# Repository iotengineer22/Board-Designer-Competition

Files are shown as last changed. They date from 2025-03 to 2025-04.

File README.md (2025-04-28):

# Board-Designer-Competition
This repository present solution for the Board Designer Competition 

[Board Designer Competition](https://www.hackster.io/contests/board-designer).

## Introduction
**First of all thank you to Nordic Semiconductor, Autodesk, PCBWay and hackster.io for hosting this exciting competition.**

The main project is primarily summarized on hackster.io, so please refer to it there 

[Maker's nRF54L15 Debug Board](https://www.hackster.io/iotengineer22/maker-s-nrf54l15-debug-board-1a6a88)

In this project, we provide Maker's nRF54L15 Debug Board. We have designed a compact board featuring the powerful nRF54L15 Wireless SOC.

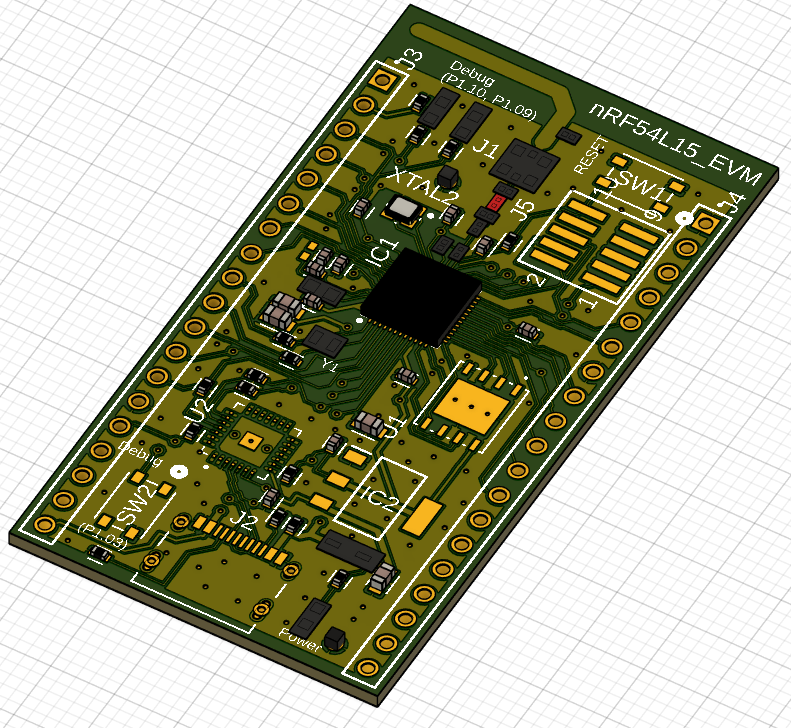
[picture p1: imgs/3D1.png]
3D1


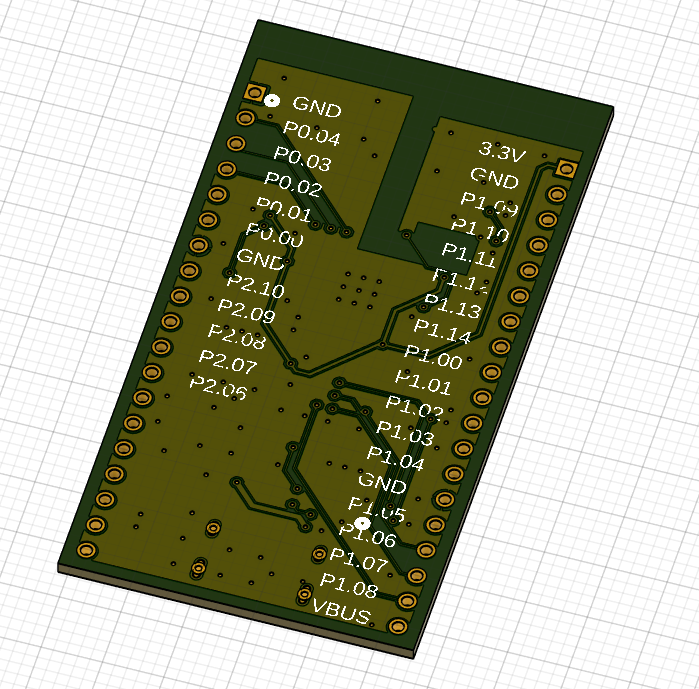
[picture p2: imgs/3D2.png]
3D2


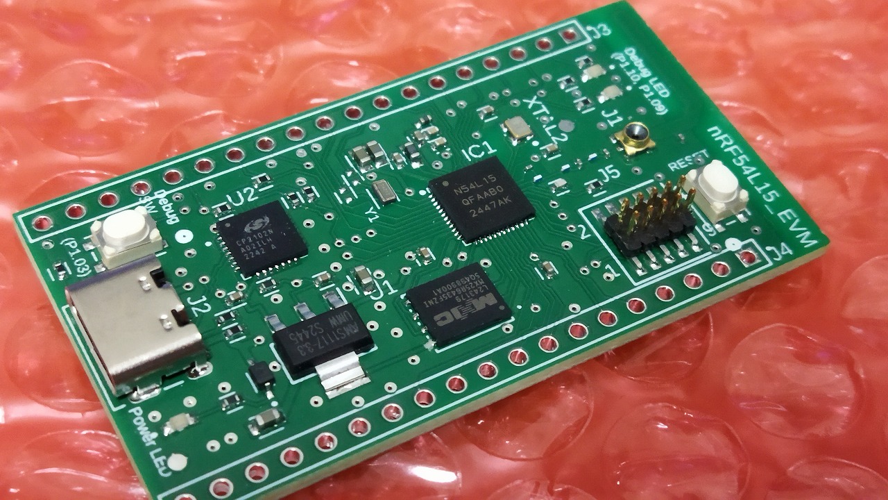
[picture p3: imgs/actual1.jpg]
ac1


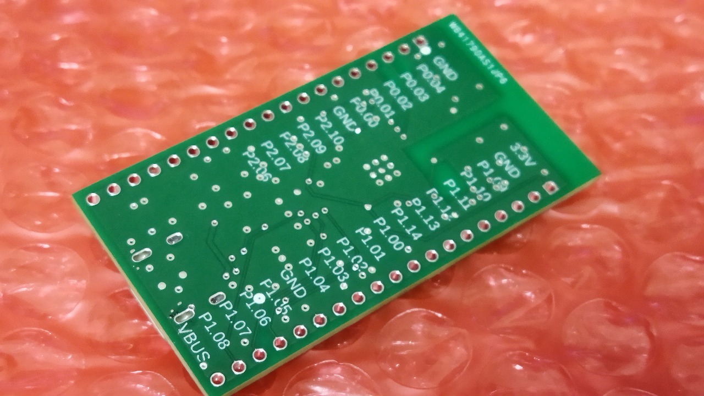
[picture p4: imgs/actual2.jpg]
ac2


## Structure
    .
    ├── pcb                 # PCB files(autodesk, gerber, bom, schematics)   
    ├── src                 # Program and board files (program, board)   
    ├── LICENSE
    └── README.md

## Electrical Diagram overview

This is Main electrical diagram.

**For details, see the PDF file.**
[PDF schematics](pcb/schematics)

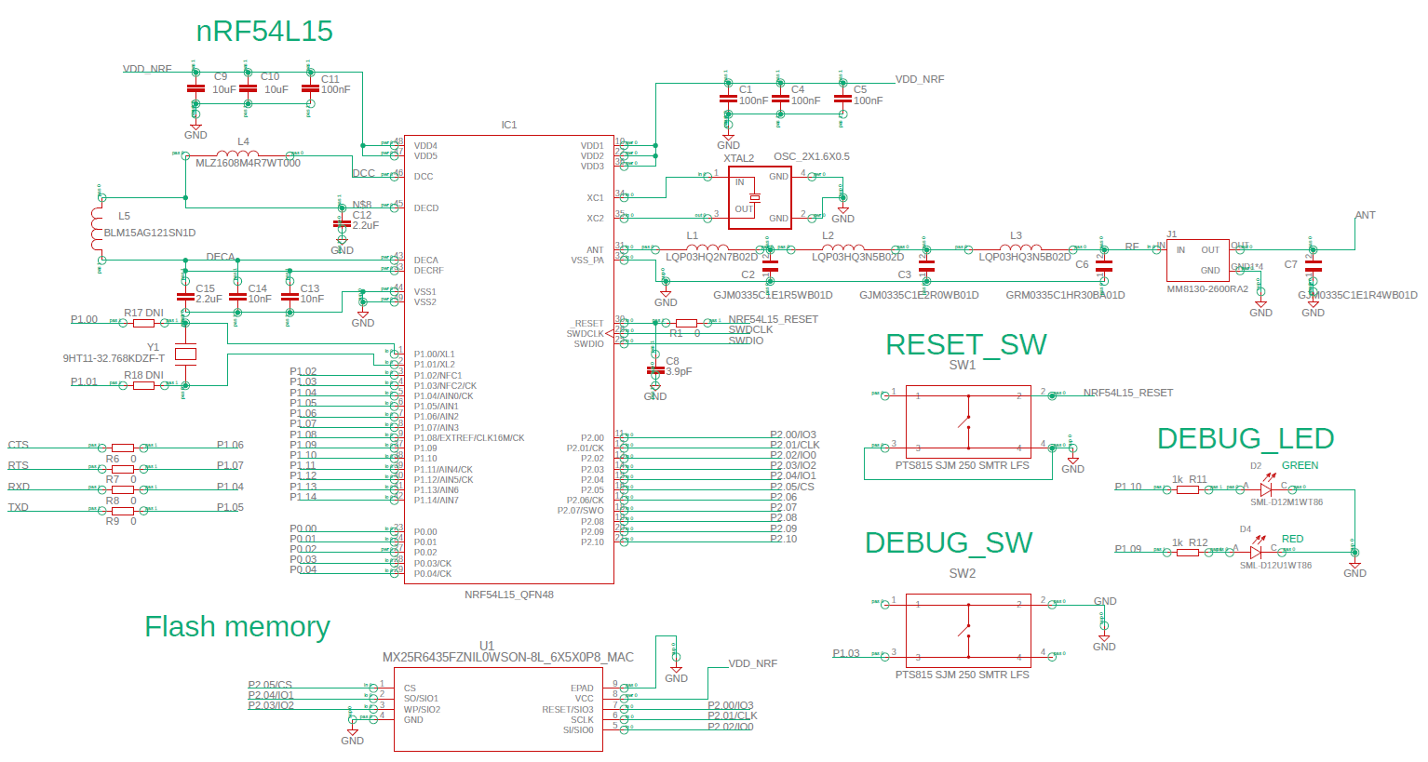
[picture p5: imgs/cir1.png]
schematics1


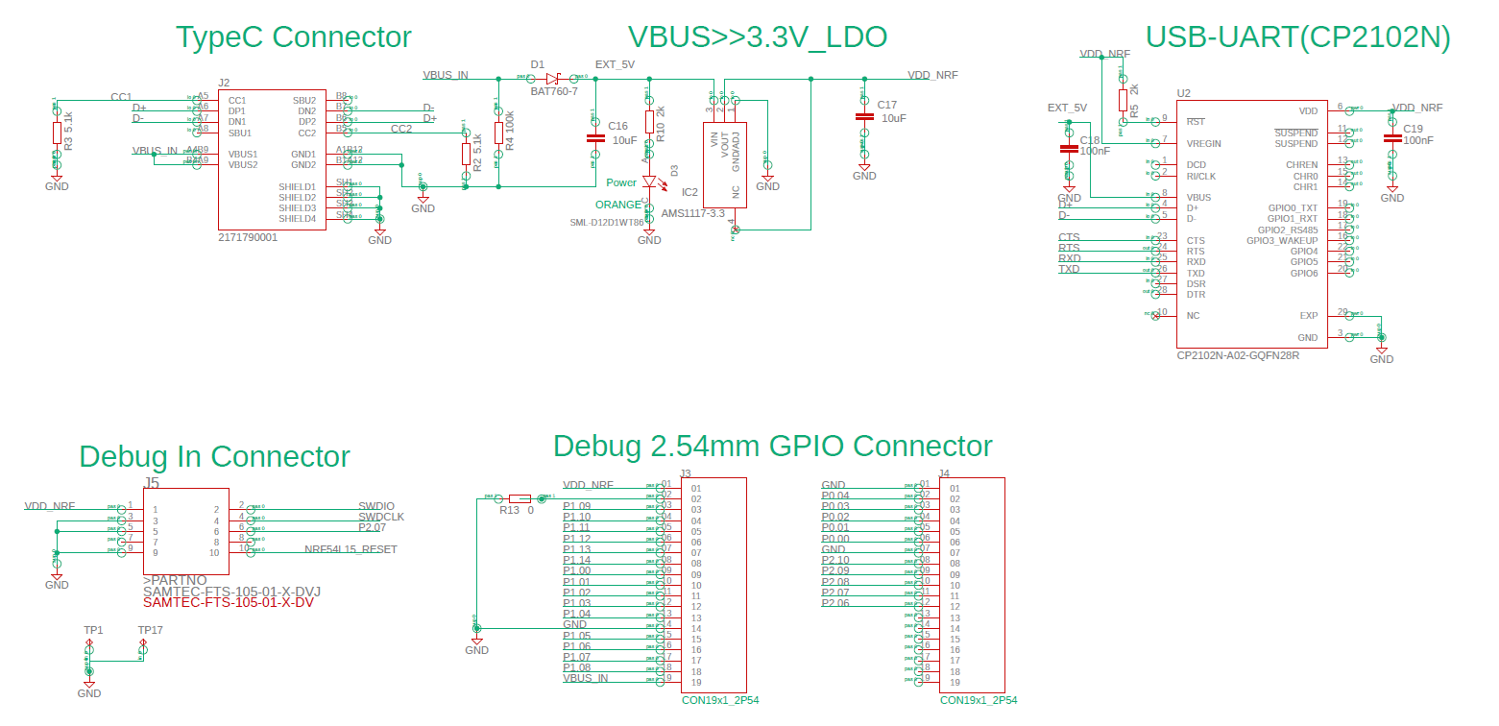
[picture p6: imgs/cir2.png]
schematics2


## PCB ArtWork overview

This is Artwork overview.

**For details, see the PCB files in Autodesk Fusion or Gerber data.**

[Autodesk_project_file](pcb/autodesk)

[Gerber_data](pcb/gerber)

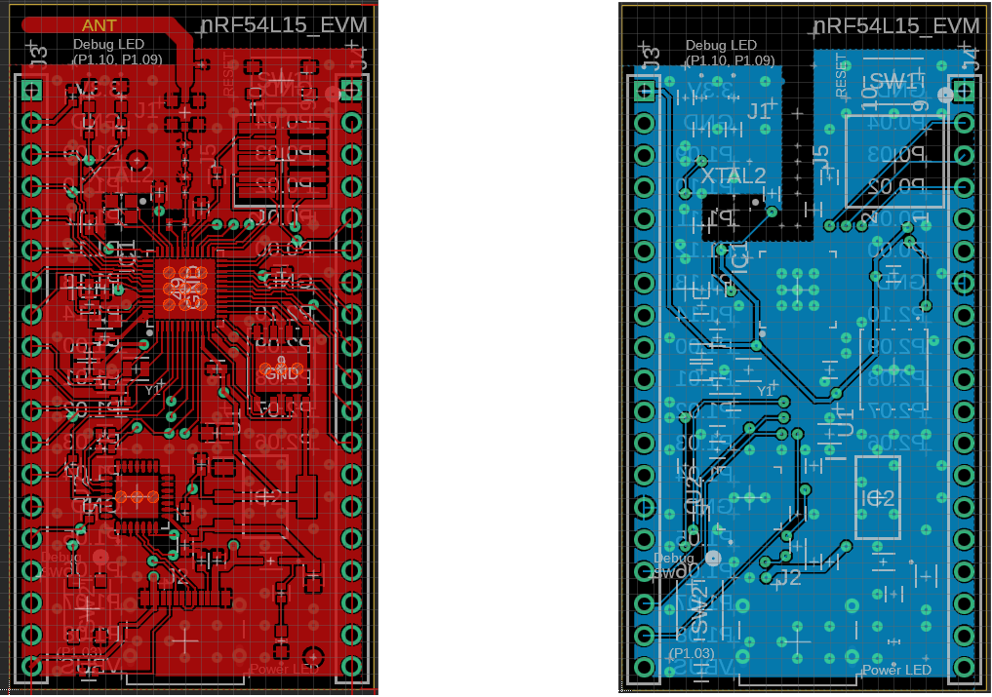
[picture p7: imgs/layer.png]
artwork1


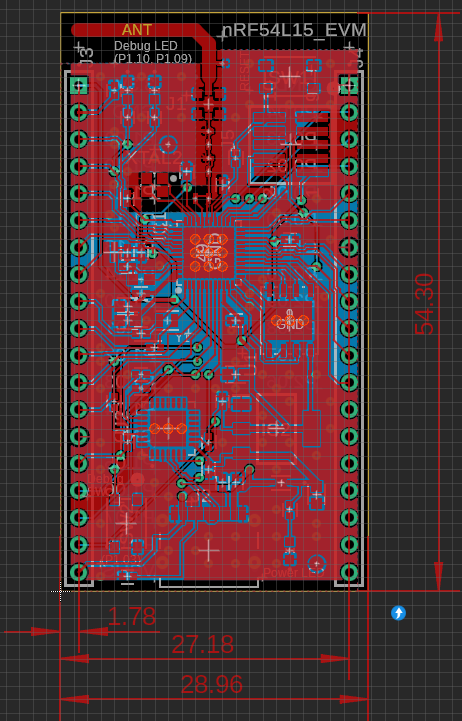
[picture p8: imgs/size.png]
artwork2


## PCB BOM

This is BOM overview.

**For details, see the BOM data(.xlsx).**

[BOM_file](pcb/bom)

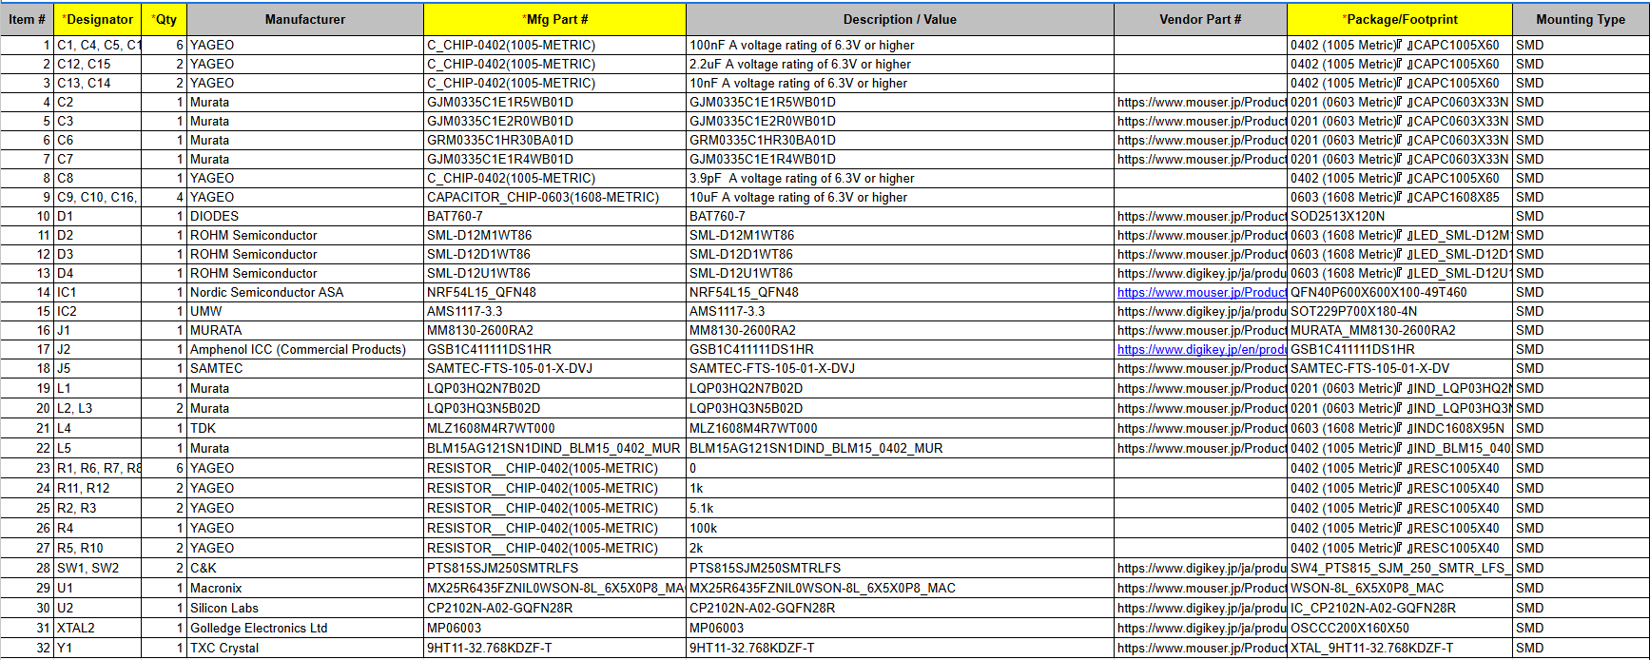
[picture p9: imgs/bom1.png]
bom1


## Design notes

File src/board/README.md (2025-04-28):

## Refernce

This board file references the following repository:https://github.com/zephyrproject-rtos/zephyr/tree/main/boards/nordic/nrf54l15dk

v2.9.0

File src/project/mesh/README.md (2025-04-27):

## Refernce

This program references the following repository:
Using the reference program directly.
https://github.com/nrfconnect/sdk-nrf/tree/main/samples/bluetooth/mesh/chat

Note: The my board file for this project does not support Non-Secure mode. Therefore, the nRF54L15-DK board file is being used for this test.

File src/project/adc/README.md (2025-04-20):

## Refernce

This program references the following repository:https://github.com/zephyrproject-rtos/zephyr/tree/main/samples/drivers/adc/adc_sequence

Note: This test requires the addition of an ADC device tree. We are using the configuration file for the nRF54L15-DK.

Make sure to configure it using "Extra Devicetree overlays" during board configuration.

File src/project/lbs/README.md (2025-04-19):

## Refernce

This program references the following repository:
https://github.com/nrfconnect/sdk-nrf/tree/main/samples/bluetooth/peripheral_lbs

Note: The my board file for this project does not support Non-Secure mode. Therefore, the nRF54L15-DK board file is being used for this test.

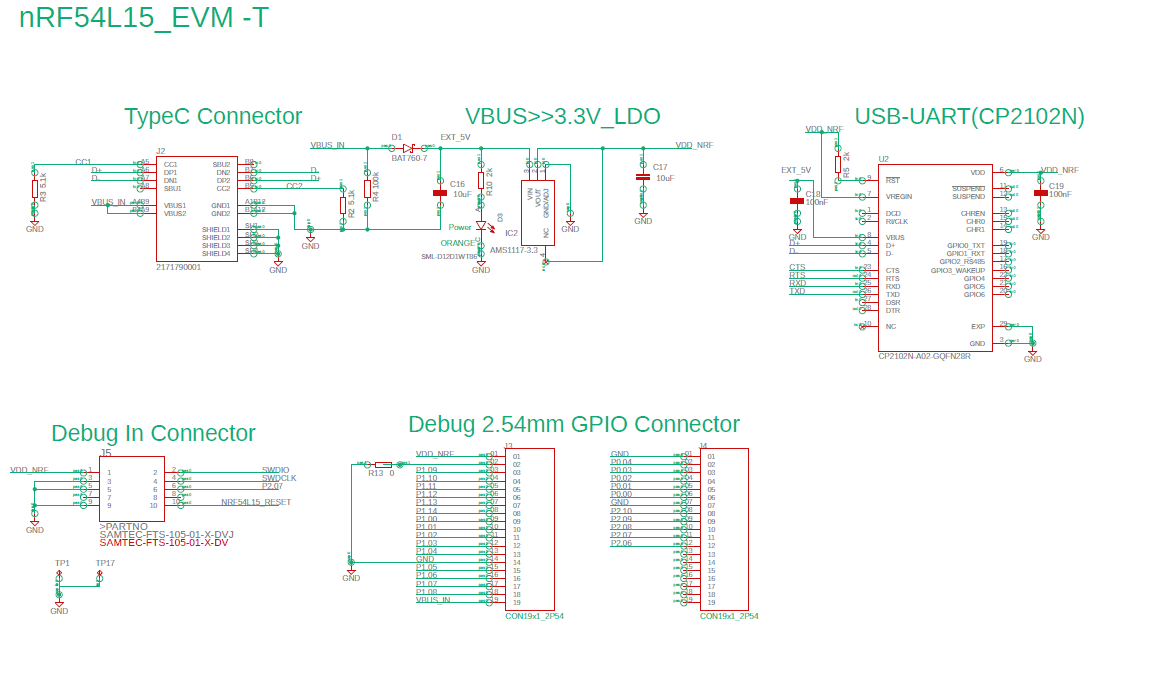
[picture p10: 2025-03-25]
imgs/schematics1.png

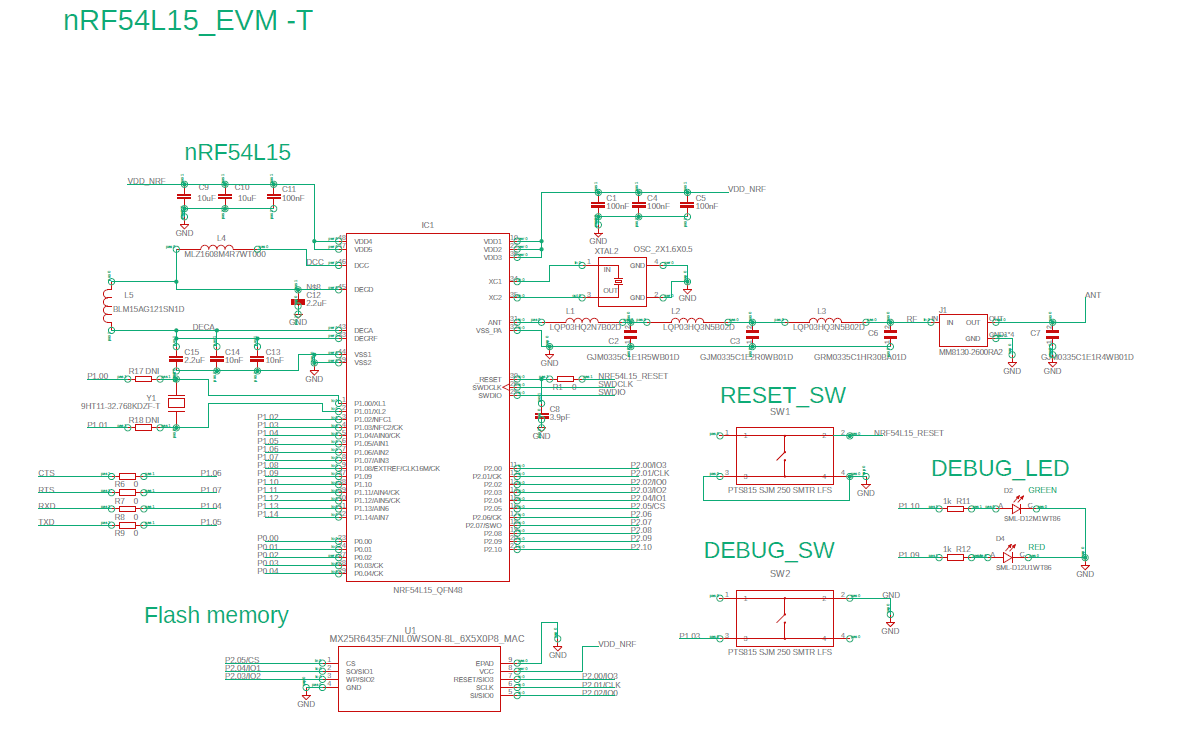
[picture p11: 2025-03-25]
imgs/schematics2.png

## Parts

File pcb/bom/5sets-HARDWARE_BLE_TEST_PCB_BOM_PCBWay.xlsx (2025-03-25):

PCBWay Bom Quotation, Product No.
Item # | *Designator | *Qty | Manufacturer | *Mfg Part # | Description / Value | Vendor Part # | *Package/Footprint | Mounting Type | *Unit Price(5 sets) | *Total | *Delivery Time | *Actual Purchase Mfg Part # | Customer Reply | PCBWay Update
1 | C1, C4, C5, C11, C18, C19 | 6 | YAGEO | C_CHIP-0402(1005-METRIC) | 100nF A voltage rating of 6.3V or higher |  | 0402 (1005 Metric)『 』CAPC1005X60 | SMD | $0.005 | $0.150 |  | CC0402KRX7R5BB104
2 | C12, C15 | 2 | YAGEO | C_CHIP-0402(1005-METRIC) | 2.2uF A voltage rating of 6.3V or higher |  | 0402 (1005 Metric)『 』CAPC1005X60 | SMD | $0.050 | $0.500 |  | CC0402MRX5R5BB225
3 | C13, C14 | 2 | YAGEO | C_CHIP-0402(1005-METRIC) | 10nF A voltage rating of 6.3V or higher |  | 0402 (1005 Metric)『 』CAPC1005X60 | SMD | $0.016 | $0.160 |  | CC0402KRX7R5BB103
4 | C2 | 1 | Murata | GJM0335C1E1R5WB01D | GJM0335C1E1R5WB01D | https://www.mouser.jp/ProductDetail/Murata-Electronics/GJM0335C1E1R5WB01D?qs=YLLXL5qGyDs1VzYPuYV7Xw%3D%3D | 0201 (0603 Metric)『 』CAPC0603X33N | SMD | $0.105 | $0.525
5 | C3 | 1 | Murata | GJM0335C1E2R0WB01D | GJM0335C1E2R0WB01D | https://www.mouser.jp/ProductDetail/Murata-Electronics/GJM0335C1E2R0WB01D?qs=YLLXL5qGyDstavpxLCdNYQ%3D%3D | 0201 (0603 Metric)『 』CAPC0603X33N | SMD | $0.088 | $0.440
6 | C6 | 1 | Murata | GRM0335C1HR30BA01D | GRM0335C1HR30BA01D | https://www.mouser.jp/ProductDetail/Murata-Electronics/GRM0335C1HR30BA01D?qs=7vGxPDjevFM20tgZc05ZRA%3D%3D | 0201 (0603 Metric)『 』CAPC0603X33N | SMD | $0.063 | $0.315
7 | C7 | 1 | Murata | GJM0335C1E1R4WB01D | GJM0335C1E1R4WB01D | https://www.mouser.jp/ProductDetail/Murata-Electronics/GJM0335C1E1R4WB01D?qs=YLLXL5qGyDv2Ga7DIq6Zqw%3D%3D | 0201 (0603 Metric)『 』CAPC0603X33N | SMD | $0.273 | $1.365
8 | C8 | 1 | YAGEO | C_CHIP-0402(1005-METRIC) | 3.9pF A voltage rating of 6.3V or higher |  | 0402 (1005 Metric)『 』CAPC1005X60 | SMD | $0.050 | $0.250 |  | CC0402BRNPO9BN3R9
9 | C9, C10, C16, C17 | 4 | YAGEO | CAPACITOR_CHIP-0603(1608-METRIC) | 10uF A voltage rating of 6.3V or higher |  | 0603 (1608 Metric)『 』CAPC1608X85 | SMD | $0.037 | $0.740 |  | CC0603MRX5R5BB106
10 | D1 | 1 | DIODES | BAT760-7 | BAT760-7 | https://www.mouser.jp/ProductDetail/Diodes-Incorporated/BAT760-7?qs=JV7lzlMm3yKDDyO09xoRbQ%3D%3D | SOD2513X120N | SMD | $0.110 | $0.550
11 | D2 | 1 | ROHM Semiconductor | SML-D12M1WT86 | SML-D12M1WT86 | https://www.mouser.jp/ProductDetail/ROHM-Semiconductor/SML-D12M1WT86?qs=M3jcYzEJUdHoswTb5Zs%252BhA%3D%3D | 0603 (1608 Metric)『 』LED_SML-D12M1WT86 | SMD | $0.169 | $0.845
12 | D3 | 1 | ROHM Semiconductor | SML-D12D1WT86 | SML-D12D1WT86 | https://www.mouser.jp/ProductDetail/ROHM-Semiconductor/SML-D12D1WT86?qs=M3jcYzEJUdEqFdUV5eljZg%3D%3D | 0603 (1608 Metric)『 』LED_SML-D12D1WT86 | SMD | $0.189 | $0.945
13 | D4 | 1 | ROHM Semiconductor | SML-D12U1WT86 | SML-D12U1WT86 | https://www.digikey.jp/ja/products/detail/rohm-semiconductor/SML-D12U1WT86/5843853 | 0603 (1608 Metric)『 』LED_SML-D12U1WT86 | SMD | $0.176 | $0.880
14 | IC1 | 1 | Nordic Semiconductor ASA | NRF54L15_QFN48 | NRF54L15_QFN48 | https://www.mouser.jp/ProductDetail/Nordic-Semiconductor/NRF54L15-CAAA-R?qs=QpmGXVUTftEz0ltGbbtKyA%3D%3D | QFN40P600X600X100-49T460 | SMD | $4.797 | $23.985 | 7-10 Workdays | NRF54L15-QFAA-R
15 | IC2 | 1 | UMW | AMS1117-3.3 | AMS1117-3.3 | https://www.digikey.jp/ja/products/detail/umw/AMS1117-3-3/17635254 | SOT229P700X180-4N | SMD | $0.110 | $0.550
16 | J1 | 1 | MURATA | MM8130-2600RA2 | MM8130-2600RA2 | https://www.mouser.jp/ProductDetail/Murata-Electronics/MM8130-2600RA2?qs=pwh76yelNxAj%2FSz0%2FLo03A%3D%3D | MURATA_MM8130-2600RA2 | SMD | $0.483 | $2.415
17 | J2 | 1 | Amphenol ICC (Commercial Products) | GSB1C411111DS1HR | GSB1C411111DS1HR | https://www.digikey.jp/en/products/detail/amphenol-cs-commercial-products/GSB1C411111DS1HR/21623895 | GSB1C411111DS1HR | SMD |  |  |  | GSB1C411111DS1HR
18 | J5 | 1 | SAMTEC | SAMTEC-FTS-105-01-X-DVJ | SAMTEC-FTS-105-01-X-DVJ | https://www.mouser.jp/ProductDetail/Samtec/FTS-105-01-F-DV?qs=FESYatJ8odJViphOhsc8lQ%3D%3D | SAMTEC-FTS-105-01-X-DV | SMD | $1.771 | $8.855 |  | FTS-105-01-F-DV
19 | L1 | 1 | Murata | LQP03HQ2N7B02D | LQP03HQ2N7B02D | https://www.mouser.jp/ProductDetail/Murata-Electronics/LQP03HQ2N7B02D?qs=Ey7%2FXF42M3c4mqXFWTJuBA%3D%3D | 0201 (0603 Metric)『 』IND_LQP03HQ2N7B02D | SMD | $0.105 | $0.525
20 | L2, L3 | 2 | Murata | LQP03HQ3N5B02D | LQP03HQ3N5B02D | https://www.mouser.jp/ProductDetail/Murata-Electronics/LQP03HQ3N5B02D?qs=Ey7%2FXF42M3czaOgYp0oGuw%3D%3D | 0201 (0603 Metric)『 』IND_LQP03HQ3N5B02D | SMD | $0.231 | $2.310
21 | L4 | 1 | TDK | MLZ1608M4R7WT000 | MLZ1608M4R7WT000 | https://www.mouser.jp/ProductDetail/TDK/MLZ1608M4R7WT000?qs=%2FPzWLGNeQ%252BgDMtsNiWmi%252BQ%3D%3D | 0603 (1608 Metric)『 』INDC1608X95N | SMD | $0.097 | $0.485
22 | L5 | 1 | Murata | BLM15AG121SN1DIND_BLM15_0402_MUR | BLM15AG121SN1DIND_BLM15_0402_MUR | https://www.mouser.jp/ProductDetail/Murata-Electronics/BLM15AG121SN1D?qs=0mZ9c%252Bni6FbHnpaodfEgFg%3D%3D | 0402 (1005 Metric)『 』IND_BLM15_0402_MUR | SMD | $0.050 | $0.250 |  | BLM15AG121SN1D
23 | R1, R6, R7, R8, R9, R13 | 6 | YAGEO | RESISTOR__CHIP-0402(1005-METRIC) | 0 |  | 0402 (1005 Metric)『 』RESC1005X40 | SMD | $0.003 | $0.090 |  | RC0402FR-070RL
24 | R11, R12 | 2 | YAGEO | RESISTOR__CHIP-0402(1005-METRIC) | 1k |  | 0402 (1005 Metric)『 』RESC1005X40 | SMD | $0.013 | $0.130 |  | RC0402FR-071KL
25 | R2, R3 | 2 | YAGEO | RESISTOR__CHIP-0402(1005-METRIC) | 5.1k |  | 0402 (1005 Metric)『 』RESC1005X40 | SMD | $0.013 | $0.130 |  | RC0402FR-075K1L
26 | R4 | 1 | YAGEO | RESISTOR__CHIP-0402(1005-METRIC) | 100k |  | 0402 (1005 Metric)『 』RESC1005X40 | SMD | $0.016 | $0.080 |  | RC0402FR-07100KL
27 | R5, R10 | 2 | YAGEO | RESISTOR__CHIP-0402(1005-METRIC) | 2k |  | 0402 (1005 Metric)『 』RESC1005X40 | SMD | $0.013 | $0.130 |  | RC0402FR-072KL
28 | SW1, SW2 | 2 | C&K | PTS815SJM250SMTRLFS | PTS815SJM250SMTRLFS | https://www.digikey.jp/ja/products/detail/c-k/PTS815-SJM-250-SMTR-LFS/9947846 | SW4_PTS815_SJM_250_SMTR_LFS_CN | SMD | $0.247 | $2.470
29 | U1 | 1 | Macronix | MX25R6435FZNIL0WSON-8L_6X5X0P8_MAC | MX25R6435FZNIL0WSON-8L_6X5X0P8_MAC | https://www.mouser.jp/ProductDetail/Macronix/MX25R6435FZNIL0-TR?qs=mELouGlnn3eItee4ycFGCQ%3D%3D | WSON-8L_6X5X0P8_MAC | SMD | $2.403 | $12.015 | 7-10 Workdays | MX25R6435FZNIL0-TR
30 | U2 | 1 | Silicon Labs | CP2102N-A02-GQFN28R | CP2102N-A02-GQFN28R | https://www.digikey.jp/ja/products/detail/silicon-labs/CP2102N-A02-GQFN28R/9863480 | IC_CP2102N-A02-GQFN28R | SMD | $2.415 | $12.075
31 | XTAL2 | 1 | Golledge Electronics Ltd | MP06003 | MP06003 | https://www.digikey.jp/ja/products/detail/golledge-electronics-ltd/MP06003/16965329 | OSCCC200X160X50 | SMD | $0.599 | $2.995 | 7-10 Workdays
32 | Y1 | 1 | TXC Crystal | 9HT11-32.768KDZF-T | 9HT11-32.768KDZF-T | https://www.mouser.jp/ProductDetail/TXC-Corporation/9HT11-32.768KDZF-T?qs=F0DCslhVfvzZjS075r2oeA%3D%3D | XTAL_9HT11-32.768KDZF-T | SMD | $1.143 | $5.715 | 7-10 Workdays
 |  |  |  |  |  |  |  |  | Component Cost | $82.87
 |  |  |  |  |  |  |  |  | Assembly Cost | $88.00
 |  |  |  |  |  |  |  |  | PCB Cost | $5.00
 |  |  |  |  |  |  |  |  | V0 Member 0% off | $0.00
 |  |  |  |  |  |  |  |  | All Total 5 Sets | $175.87

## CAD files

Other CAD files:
pcb/autodesk/hardware_ble_test v68.f3z

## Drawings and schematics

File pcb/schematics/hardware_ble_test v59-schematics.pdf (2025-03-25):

pas 1 | pas 1 pas 0 pas 1 | pas 1 pas 1 | pas 1 pas 1

# nRF54L15

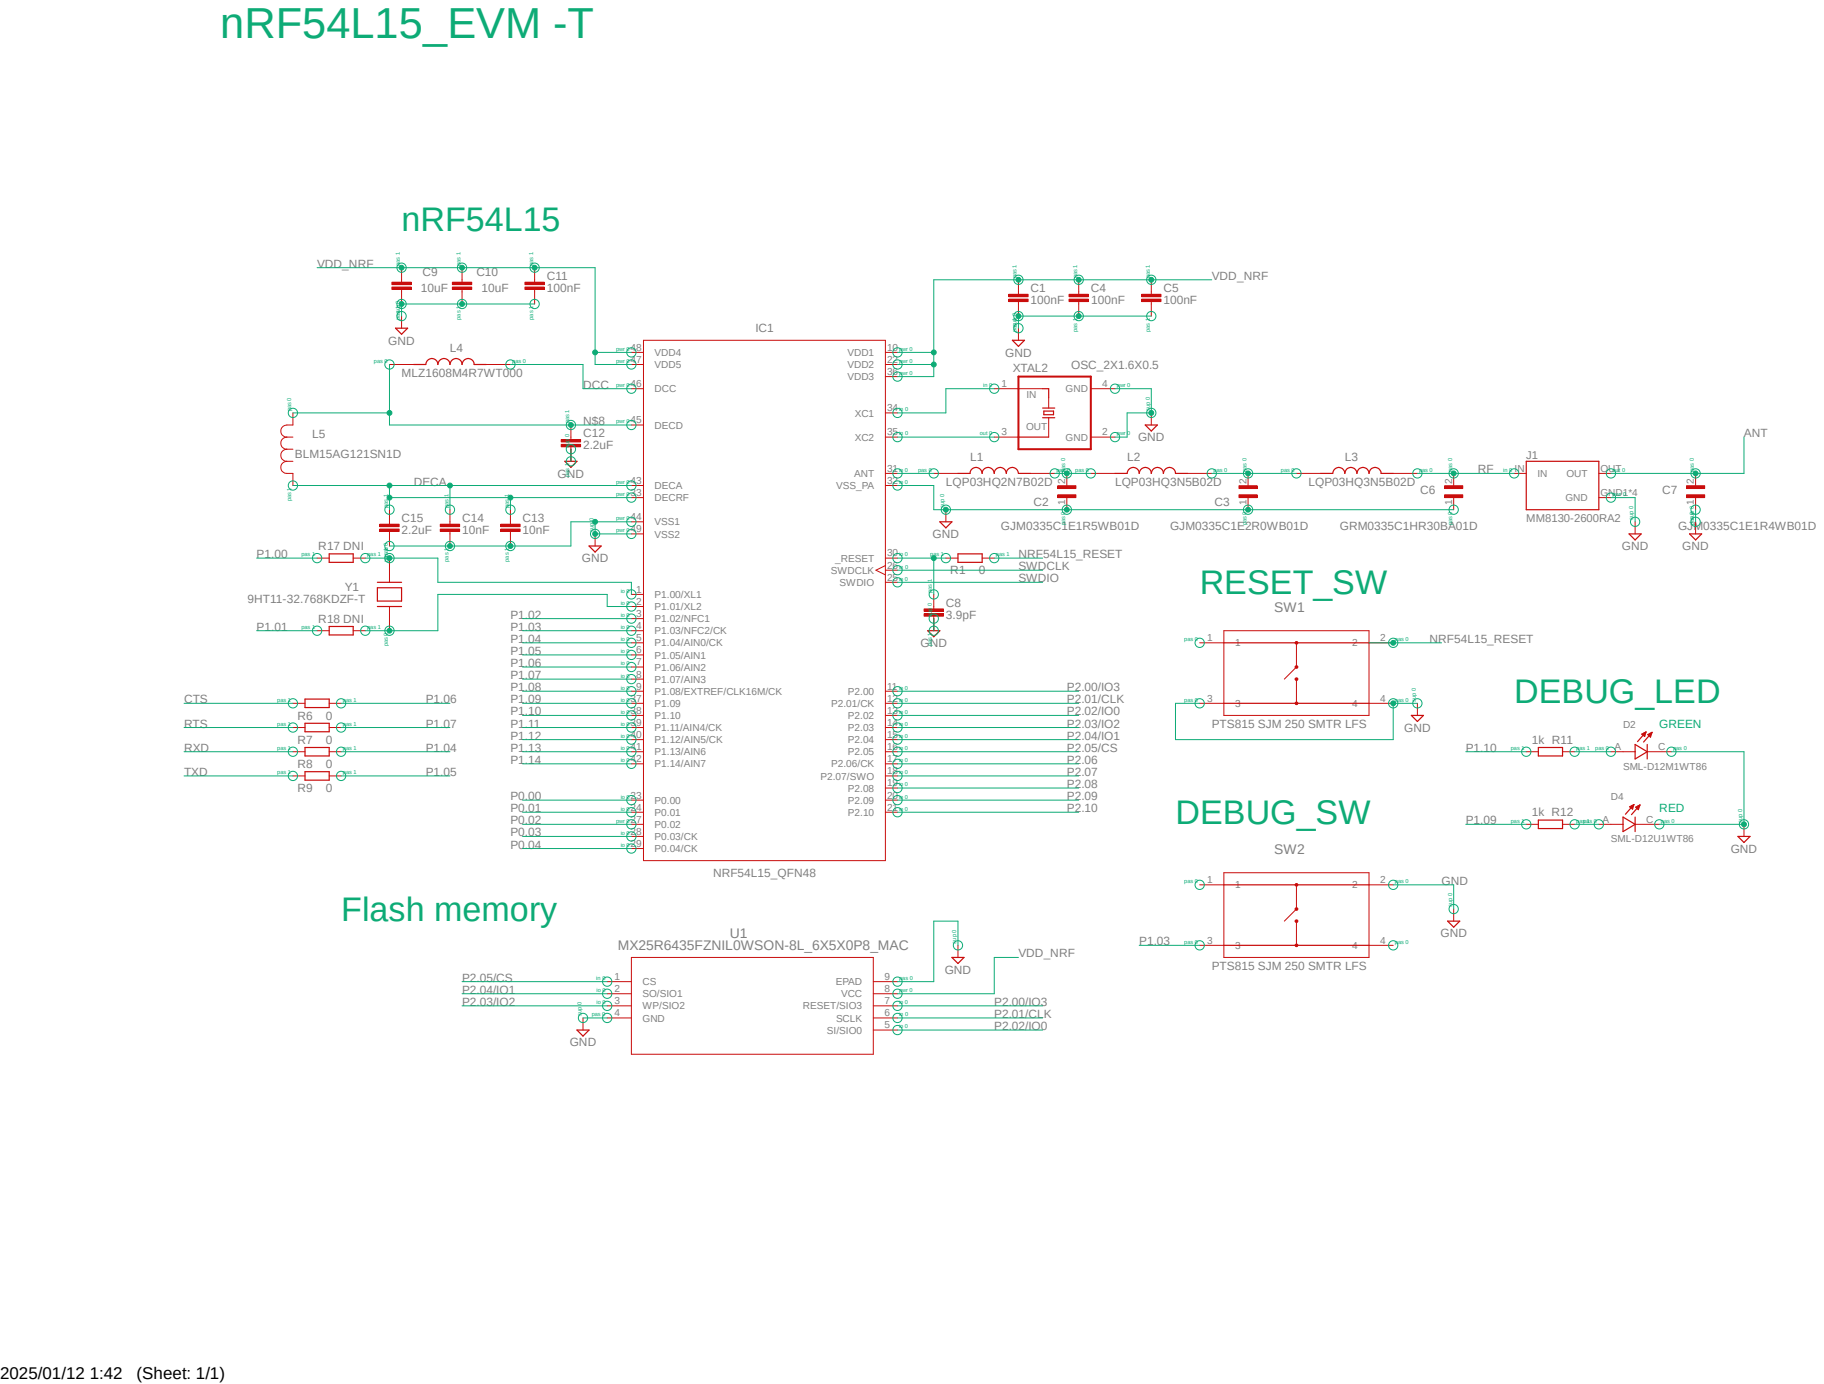
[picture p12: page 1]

pwr 0

SAMTEC-FTS-105-01-X-DV in 0 sup 0 | sup 0

# TypeC Connector

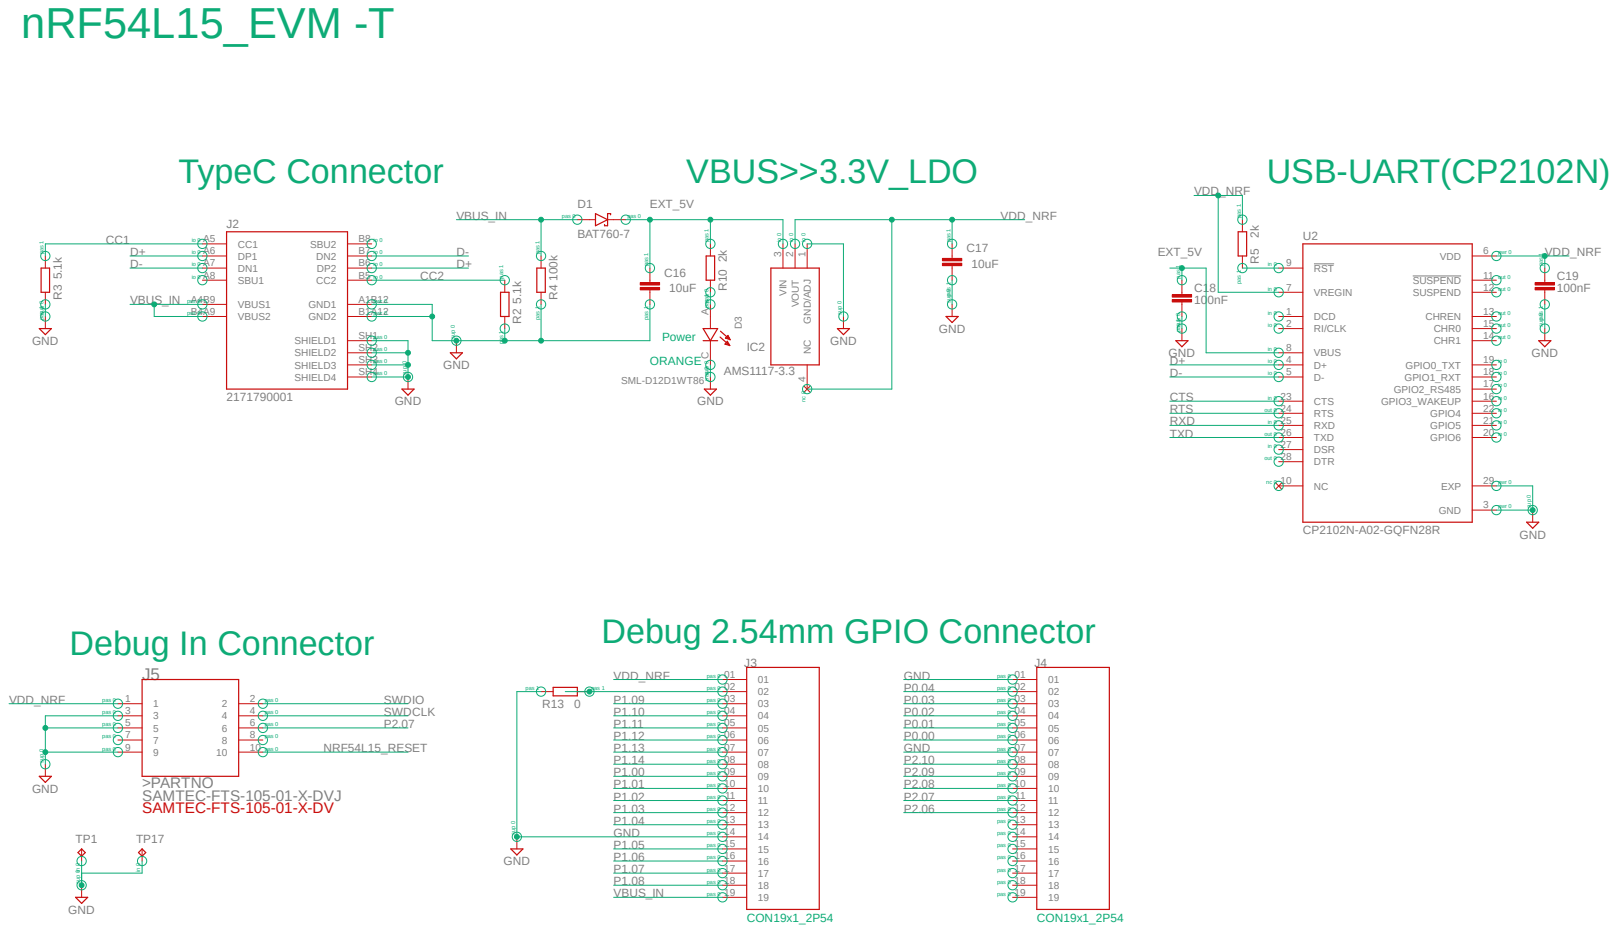
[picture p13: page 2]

5 pas 0 | 6 P2.07 pas 0
7 pas 0 9 | 8 pas 0 NRF54L15_RESET

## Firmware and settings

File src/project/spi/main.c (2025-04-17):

/*
 * Copyright (c) 2016 Intel Corporation.
 *
 * SPDX-License-Identifier: Apache-2.0
 */

#include <zephyr/kernel.h>
#include <zephyr/drivers/flash.h>
#include <zephyr/device.h>
#include <zephyr/devicetree.h>
#include <stdio.h>
#include <string.h>

#if defined(CONFIG_BOARD_ADAFRUIT_FEATHER_STM32F405)
#define SPI_FLASH_TEST_REGION_OFFSET 0xf000
#elif defined(CONFIG_BOARD_ARTY_A7_DESIGNSTART_FPGA_CORTEX_M1) || \
	defined(CONFIG_BOARD_ARTY_A7_DESIGNSTART_FPGA_CORTEX_M3)
/* The FPGA bitstream is stored in the lower 536 sectors of the flash. */
#define SPI_FLASH_TEST_REGION_OFFSET \
	DT_REG_SIZE(DT_NODE_BY_FIXED_PARTITION_LABEL(fpga_bitstream))
#elif defined(CONFIG_BOARD_NPCX9M6F_EVB) || \
	defined(CONFIG_BOARD_NPCX7M6FB_EVB)
#define SPI_FLASH_TEST_REGION_OFFSET 0x7F000
#else
#define SPI_FLASH_TEST_REGION_OFFSET 0xff000
#endif
#define SPI_FLASH_SECTOR_SIZE        4096

#if defined(CONFIG_FLASH_STM32_OSPI) || \
	defined(CONFIG_FLASH_STM32_QSPI) || \
	defined(CONFIG_FLASH_STM32_XSPI)
#define SPI_FLASH_MULTI_SECTOR_TEST
#endif

#if DT_HAS_COMPAT_STATUS_OKAY(jedec_spi_nor)
#define SPI_FLASH_COMPAT jedec_spi_nor
#elif DT_HAS_COMPAT_STATUS_OKAY(st_stm32_qspi_nor)
#define SPI_FLASH_COMPAT st_stm32_qspi_nor
#elif DT_HAS_COMPAT_STATUS_OKAY(st_stm32_ospi_nor)
#define SPI_FLASH_COMPAT st_stm32_ospi_nor
#elif DT_HAS_COMPAT_STATUS_OKAY(st_stm32_xspi_nor)
#define SPI_FLASH_COMPAT st_stm32_xspi_nor
#elif DT_HAS_COMPAT_STATUS_OKAY(nordic_qspi_nor)
#define SPI_FLASH_COMPAT nordic_qspi_nor
#else
#define SPI_FLASH_COMPAT invalid
#endif

const uint8_t erased[] = { 0xff, 0xff, 0xff, 0xff };

void single_sector_test(const struct device *flash_dev)
{
	const uint8_t expected[] = { 0x55, 0xaa, 0x66, 0x99 };
	const size_t len = sizeof(expected);
	uint8_t buf[sizeof(expected)];
	int rc;

	printf("\nPerform test on single sector");
	/* Write protection needs to be disabled before each write or
	 * erase, since the flash component turns on write protection
	 * automatically after completion of write and erase
	 * operations.
	 */
	printf("\nTest 1: Flash erase\n");

	/* Full flash erase if SPI_FLASH_TEST_REGION_OFFSET = 0 and
	 * SPI_FLASH_SECTOR_SIZE = flash size
	 */
	rc = flash_erase(flash_dev, SPI_FLASH_TEST_REGION_OFFSET,
			 SPI_FLASH_SECTOR_SIZE);
	if (rc != 0) {
		printf("Flash erase failed! %d\n", rc);
	} else {
		/* Check erased pattern */
		memset(buf, 0, len);
		rc = flash_read(flash_dev, SPI_FLASH_TEST_REGION_OFFSET, buf, len);
		if (rc != 0) {
			printf("Flash read failed! %d\n", rc);
			return;
		}
		if (memcmp(erased, buf, len) != 0) {
			printf("Flash erase failed at offset 0x%x got 0x%x\n",
				SPI_FLASH_TEST_REGION_OFFSET, *(uint32_t *)buf);
			return;
		}
		printf("Flash erase succeeded!\n");
	}
	printf("\nTest 2: Flash write\n");

	// Add this section to print the bytes being written
	printf("Bytes to be written: ");
	for (size_t i = 0; i < len; ++i) {
		printf("0x%02x ", expected[i]);
	}
	printf("\n");
	// End of added section

	printf("Attempting to write %zu bytes\n", len);
	rc = flash_write(flash_dev, SPI_FLASH_TEST_REGION_OFFSET, expected, len);
	if (rc != 0) {
		printf("Flash write failed! %d\n", rc);
		return;
	}

	memset(buf, 0, len);
	rc = flash_read(flash_dev, SPI_FLASH_TEST_REGION_OFFSET, buf, len);
	if (rc != 0) {
		printf("Flash read failed! %d\n", rc);
		return;
	}

	// Add this section to print the bytes being read
	printf("Bytes read back: ");
	for (size_t i = 0; i < len; ++i) {
		printf("0x%02x ", buf[i]);
	}
	printf("\n");
	// End of added section	

	if (memcmp(expected, buf, len) == 0) {
		printf("Data read matches data written. Good!!\n");
	} else {
		const uint8_t *wp = expected;
		const uint8_t *rp = buf;
		const uint8_t *rpe = rp + len;

		printf("Data read does not match data written!!\n");
		while (rp < rpe) {
			printf("%08x wrote %02x read %02x %s\n",
			       (uint32_t)(SPI_FLASH_TEST_REGION_OFFSET + (rp - buf)),
			       *wp, *rp, (*rp == *wp) ? "match" : "MISMATCH");
			++rp;
			++wp;
		}
	}
}

#if defined SPI_FLASH_MULTI_SECTOR_TEST
void multi_sector_test(const struct device *flash_dev)
{
	const uint8_t expected[] = { 0x55, 0xaa, 0x66, 0x99 };
	const size_t len = sizeof(expected);
	uint8_t buf[sizeof(expected)];
	int rc;

	printf("\nPerform test on multiple consecutive sectors");

	/* Write protection needs to be disabled before each write or
	 * erase, since the flash component turns on write protection
	 * automatically after completion of write and erase
	 * operations.
	 */
	printf("\nTest 1: Flash erase\n");

	/* Full flash erase if SPI_FLASH_TEST_REGION_OFFSET = 0 and
	 * SPI_FLASH_SECTOR_SIZE = flash size
	 * Erase 2 sectors for check for erase of consequtive sectors
	 */
	rc = flash_erase(flash_dev, SPI_FLASH_TEST_REGION_OFFSET, SPI_FLASH_SECTOR_SIZE * 2);
	if (rc != 0) {
		printf("Flash erase failed! %d\n", rc);
	} else {
		/* Read the content and check for erased */
		memset(buf, 0, len);
		size_t offs = SPI_FLASH_TEST_REGION_OFFSET;

		while (offs < SPI_FLASH_TEST_REGION_OFFSET + 2 * SPI_FLASH_SECTOR_SIZE) {
			rc = flash_read(flash_dev, offs, buf, len);
			if (rc != 0) {
				printf("Flash read failed! %d\n", rc);
				return;
			}
			if (memcmp(erased, buf, len) != 0) {
				printf("Flash erase failed at offset 0x%x got 0x%x\n",
				offs, *(uint32_t *)buf);
				return;
			}
			offs += SPI_FLASH_SECTOR_SIZE;
		}
		printf("Flash erase succeeded!\n");
	}

	printf("\nTest 2: Flash write\n");

	size_t offs = SPI_FLASH_TEST_REGION_OFFSET;

	while (offs < SPI_FLASH_TEST_REGION_OFFSET + 2 * SPI_FLASH_SECTOR_SIZE) {
		printf("Attempting to write %zu bytes at offset 0x%x\n", len, offs);
		rc = flash_write(flash_dev, offs, expected, len);
		if (rc != 0) {
			printf("Flash write failed! %d\n", rc);
			return;
		}

		memset(buf, 0, len);
		rc = flash_read(flash_dev, offs, buf, len);
		if (rc != 0) {
			printf("Flash read failed! %d\n", rc);
			return;
		}

		if (memcmp(expected, buf, len) == 0) {
			printf("Data read matches data written. Good!!\n");
		} else {
			const uint8_t *wp = expected;
			const uint8_t *rp = buf;
			const uint8_t *rpe = rp + len;

			printf("Data read does not match data written!!\n");
			while (rp < rpe) {
				printf("%08x wrote %02x read %02x %s\n",
					(uint32_t)(offs + (rp - buf)),
					*wp, *rp, (*rp == *wp) ? "match" : "MISMATCH");
				++rp;
				++wp;
			}
		}
		offs += SPI_FLASH_SECTOR_SIZE;
	}
}
#endif

int main(void)
{
	const struct device *flash_dev = DEVICE_DT_GET_ONE(SPI_FLASH_COMPAT);

	if (!device_is_ready(flash_dev)) {
		printk("%s: device not ready.\n", flash_dev->name);
		return 0;
	}

	printf("\n%s SPI flash testing\n", flash_dev->name);
	printf("==========================\n");

	single_sector_test(flash_dev);
#if defined SPI_FLASH_MULTI_SECTOR_TEST
	multi_sector_test(flash_dev);
#endif
	return 0;
}

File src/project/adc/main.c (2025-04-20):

/*
 * Copyright (c) 2024 Centro de Inovacao EDGE
 *
 * SPDX-License-Identifier: Apache-2.0
 */

#include <zephyr/drivers/adc.h>
#include <zephyr/kernel.h>

/* ADC node from the devicetree. */
#define ADC_NODE DT_ALIAS(adc0)

/* Auxiliary macro to obtain channel vref, if available. */
#define CHANNEL_VREF(node_id) DT_PROP_OR(node_id, zephyr_vref_mv, 0)

/* Data of ADC device specified in devicetree. */
static const struct device *adc = DEVICE_DT_GET(ADC_NODE);

/* Data array of ADC channels for the specified ADC. */
static const struct adc_channel_cfg channel_cfgs[] = {
	DT_FOREACH_CHILD_SEP(ADC_NODE, ADC_CHANNEL_CFG_DT, (,))};

/* Data array of ADC channel voltage references. */
static uint32_t vrefs_mv[] = {DT_FOREACH_CHILD_SEP(ADC_NODE, CHANNEL_VREF, (,))};

/* Get the number of channels defined on the DTS. */
#define CHANNEL_COUNT ARRAY_SIZE(channel_cfgs)

int main(void)
{
	int err;
	uint32_t count = 0;
	uint16_t channel_reading[CONFIG_SEQUENCE_SAMPLES][CHANNEL_COUNT];

	/* Options for the sequence sampling. */
	const struct adc_sequence_options options = {
		.extra_samplings = CONFIG_SEQUENCE_SAMPLES - 1,
		.interval_us = 0,
	};

	/* Configure the sampling sequence to be made. */
	struct adc_sequence sequence = {
		.buffer = channel_reading,
		/* buffer size in bytes, not number of samples */
		.buffer_size = sizeof(channel_reading),
		.resolution = CONFIG_SEQUENCE_RESOLUTION,
		.options = &options,
	};

	if (!device_is_ready(adc)) {
		printf("ADC controller device %s not ready\n", adc->name);
		return 0;
	}

	/* Configure channels individually prior to sampling. */
	for (size_t i = 0U; i < CHANNEL_COUNT; i++) {
		sequence.channels |= BIT(channel_cfgs[i].channel_id);
		err = adc_channel_setup(adc, &channel_cfgs[i]);
		if (err < 0) {
			printf("Could not setup channel #%d (%d)\n", i, err);
			return 0;
		}
		if (channel_cfgs[i].reference == ADC_REF_INTERNAL) {
			vrefs_mv[i] = adc_ref_internal(adc);
		}
	}

#ifndef CONFIG_COVERAGE
	while (1) {
#else
	for (int k = 0; k < 10; k++) {
#endif
		printf("ADC sequence reading [%u]:\n", count++);
		k_msleep(1000);

		err = adc_read(adc, &sequence);
		if (err < 0) {
			printf("Could not read (%d)\n", err);
			continue;
		}

		for (size_t channel_index = 0U; channel_index < CHANNEL_COUNT; channel_index++) {
			int32_t val_mv;

			printf("- %s, channel %" PRId32 ", %" PRId32 " sequence samples:\n",
			       adc->name, channel_cfgs[channel_index].channel_id,
			       CONFIG_SEQUENCE_SAMPLES);
			for (size_t sample_index = 0U; sample_index < CONFIG_SEQUENCE_SAMPLES;
			     sample_index++) {

				val_mv = channel_reading[sample_index][channel_index];

				printf("- - %" PRId32, val_mv);
				err = adc_raw_to_millivolts(vrefs_mv[channel_index],
							    channel_cfgs[channel_index].gain,
							    CONFIG_SEQUENCE_RESOLUTION, &val_mv);

				// /* conversion to mV may not be supported, skip if not */
				if ((err < 0) || vrefs_mv[channel_index] == 0) {
					printf(" (value in mV not available)\n");
				} else {
					printf(" = %" PRId32 "mV\n", val_mv);
				}
			}
		}
	}

	return 0;
}
